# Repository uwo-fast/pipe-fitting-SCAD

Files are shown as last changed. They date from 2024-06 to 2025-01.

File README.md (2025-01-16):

# pipe-fitting-SCAD

OpenSCAD script for generating pipe fittings parametrically.

## Overview

This repository contains a script for modeling a pipe fitting assembly, complete with gaskets, threaded nuts, and customizable pipe fittings. The script is designed for use in OpenSCAD and offers extensive customization for each component while adhering to existing industry thread standards.

**Note:** By using this library, you accept full personal responsibility for its use and any resulting outcomes, and irrevocably agree to the terms outlined in the [legal disclaimer](docs/DISCLAIMER.md). _In short, you are agreeing to assume all risks associated with its use._

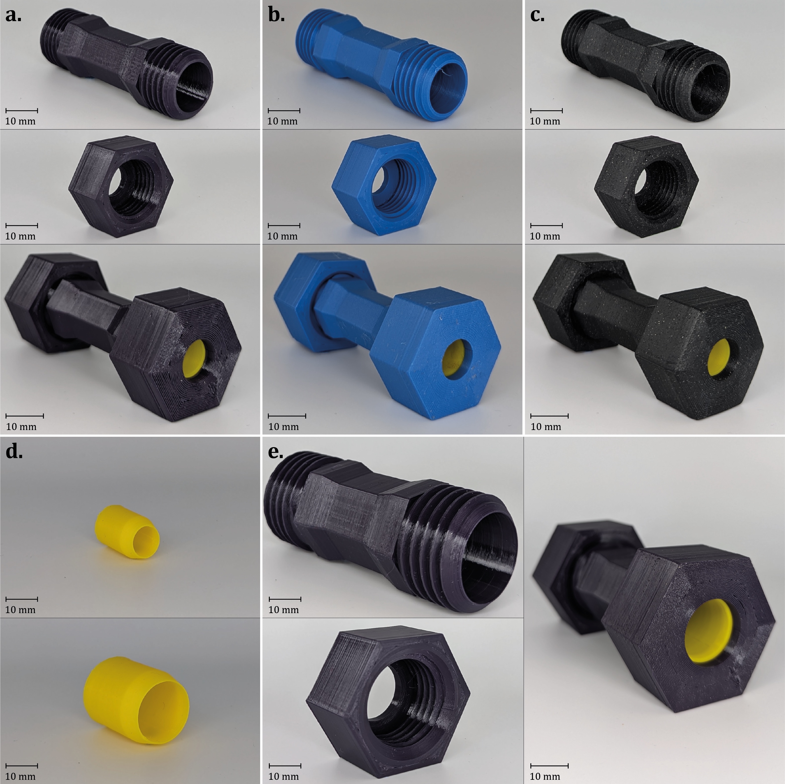
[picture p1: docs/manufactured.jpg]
Images of the Manufactured Pipe Fitting 1


## Dependencies

- OpenSCAD software.
- `threadlib` library by adrianschlatter, available at [adrianschlatter/threadlib](https://github.com/adrianschlatter/threadlib).

## Installation

1. Ensure OpenSCAD is installed on your system.
2. Download the `threadlib` library as well as this `pipe-fitting-scad` library.
3. Place both libraries in the OpenSCAD libraries directory (typically at `C:\Program Files\OpenSCAD\libraries` on Windows).

## Usage

### Creating your Fitting

Modify the dimensional variables at the beginning of the pfDesigner.scad script to customize the pipe, gasket, fitting, nuts, and threads.

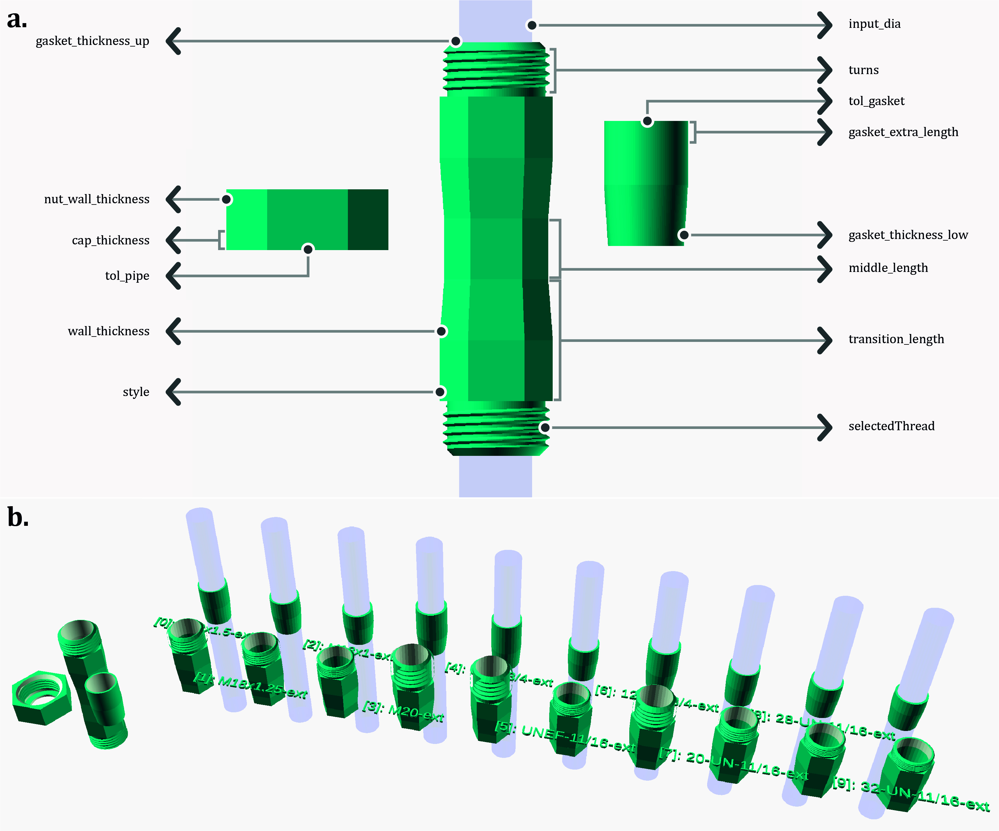
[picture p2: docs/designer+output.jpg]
Designer Interface and Labelled Output


### Manufacturing your Fitting

_Add part here about pettings and materials from paper._

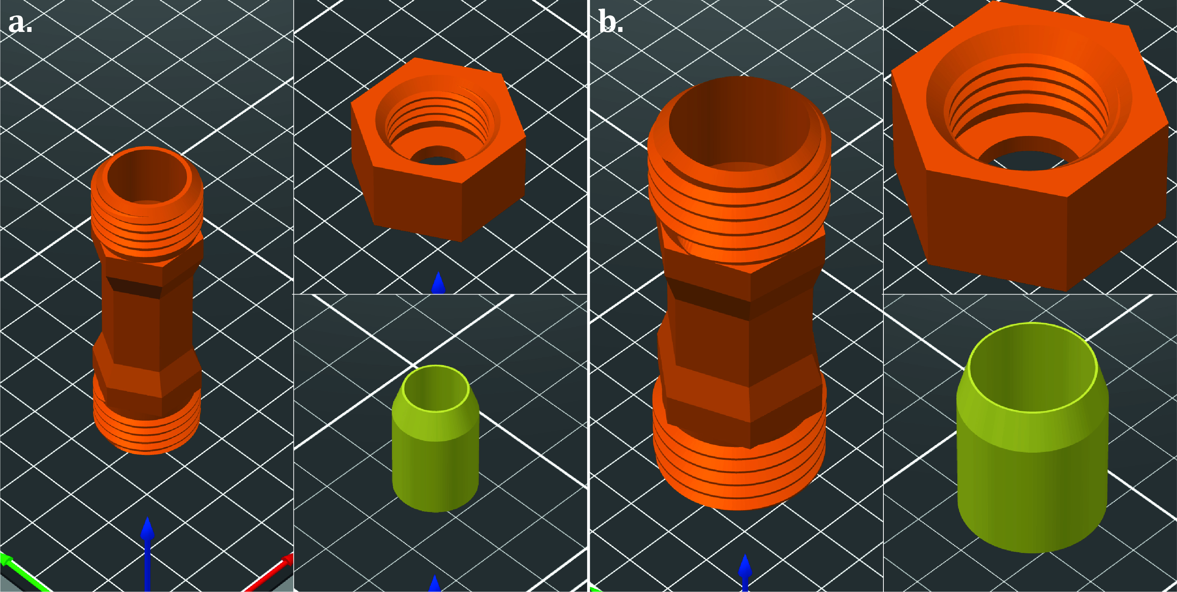
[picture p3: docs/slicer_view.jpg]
Slicer View for Manufacturing Fittings


### Performance Testing

NOTE THIS IS NOT A GAURENTEE OF SAFETY, ALWAYS CONDUCT YOUR OWN TESTING AND ALWAYS TAKE PROPER SAFETY PERCAUTIONS WHEN WORKING WITH HIGH PRESSURES.
_Add a laymans terms of the results from the paper here._

Fractured Print After Being Subject to Pressure

## How it Works

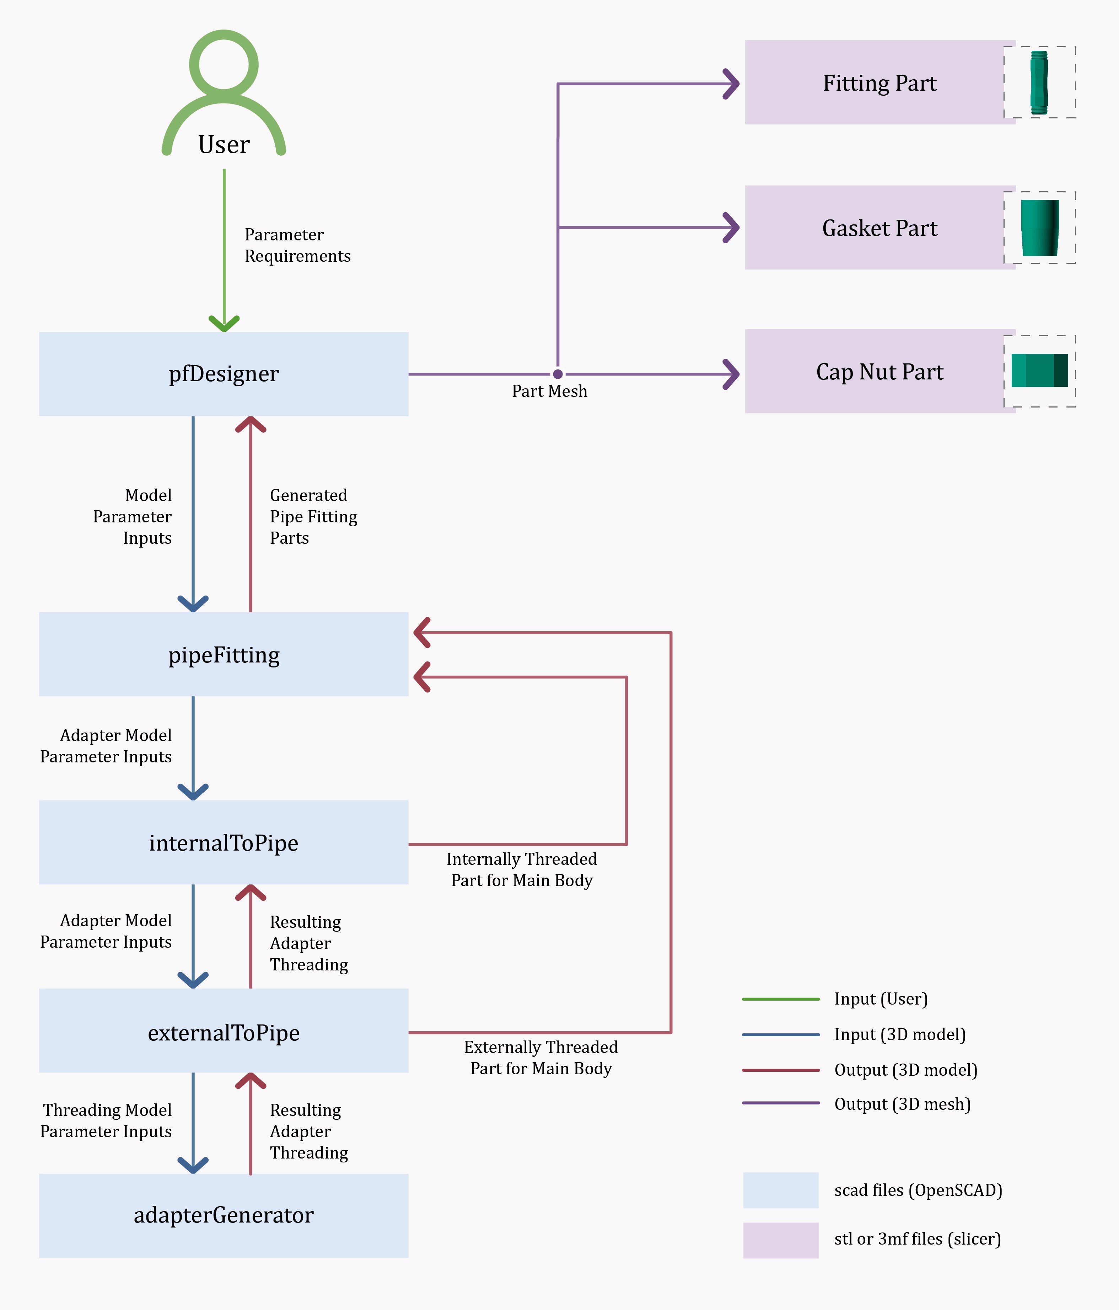
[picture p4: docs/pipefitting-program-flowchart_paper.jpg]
Programming Overview Flowchart


## Contributing & Requests

Contributions to improve the script or extend its capabilities are welcome. Please submit pull requests with clear descriptions of changes and additions. Similarly, submit an issue to request a fix or addition with a clear description of the bug or feature to be addressed.

## License

This script is licensed under the GPL 3.0 or later. For more details, see the [LICENSE](LICENSE) file.

## Acknowledgement

This was originally created by Cameron Brooks under the auspices of [FAST Research Group](https://www.appropedia.org/FAST) and published in [add when published]. This design uses [threadlib by Adrian Schlatter](https://github.com/adrianschlatter/threadlib) and inspiration from [Makrokaba's pipe joint generator](https://www.thingiverse.com/thing:4323468/files).

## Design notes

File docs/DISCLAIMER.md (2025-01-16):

# Legal Disclaimer

**By using this script and the associated files in this repository, you agree to the following terms and conditions. If you do not agree with these terms, you must immediately discontinue use of the repository and its contents.**

## 1. No Warranty

This repository, including the script and all associated files, is provided "as is," without any warranty of any kind, express or implied, including but not limited to the warranties of merchantability, fitness for a particular purpose, and non-infringement. The authors make no representations or warranties that the script will meet your requirements, be error-free, or function without interruption.

## 2. No Liability

The authors of this repository are not responsible for any damages, including but not limited to, direct, indirect, incidental, special, or consequential damages, or any loss of profits, data, or goodwill, arising from the use of this repository, even if the authors have been advised of the possibility of such damages. By using this repository, you agree to indemnify, defend, and hold harmless the authors from any claims or legal actions arising out of your use of the script or its results.

## 3. Use at Your Own Risk

The pipe fitting script, when used for 3D printing or other manufacturing methods, may result in a physical product that could fail under certain conditions, including but not limited to mechanical stress, pressure, temperature variations, or manufacturing defects. The use of this repository for creating pipe fittings or similar components is entirely at your own risk. You are responsible for ensuring the safety and integrity of any 3D printed models and components, especially in applications involving high pressures or other hazardous conditions.

## 4. Testing and Verification

The results and tests presented in this repository are provided for informational purposes only. The authors do not guarantee the safety, performance, or reliability of any 3D printed pipe fitting created using this script. It is your responsibility to perform proper testing and validation of any components you produce with this script, including pressure testing and other safety assessments. Always take appropriate safety precautions when working with high-pressure systems.

## 5. Customization and Modifications

You are permitted to modify and adapt the script to suit your needs, provided that all modifications remain subject to the terms of the GPL 3.0 license. However, any modifications or use of the repository do not absolve you of responsibility for any potential consequences arising from your use or the use of modified versions of this repository.

## 6. Compliance with Local Laws and Regulations

You are responsible for ensuring that your use of this repository and any resulting products comply with applicable laws, regulations, and safety standards in your jurisdiction. This includes, but is not limited to, compliance with engineering standards, manufacturing practices, and safety regulations for pressure vessels, piping systems, and materials.

## 7. Limitation of Use

This script is intended for use by individuals with appropriate knowledge of 3D printing, parametric design, and relevant safety protocols. It is not intended for use in mission-critical, life-threatening, or safety-critical applications. The authors disclaim any responsibility for any such usage.

## 8. Acknowledgement

By using this repository, you acknowledge that you have read and understood this legal disclaimer and agree to be bound by its terms. If you do not agree to these terms, you must refrain from using the repository or its contents.

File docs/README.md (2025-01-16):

# Docs

Welcome to the docs, right now there's not much here but that will change very soon!

## Considerations

General Considerations for 3D Printed Plumbing and HVAC Connectors:

- **Material Selection:** Must be durable, able to withstand the temperatures and pressures of refrigerant gases, and resistant to chemical degradation.

- **Dimensional Accuracy:** Essential for ensuring that fittings are leak-proof and compatible with existing pipes and components.

- **Structural Integrity:** The connectors must be able to withstand mechanical stresses without failing.

- **Compatibility with Seals and Gaskets:** Surfaces should be smooth to not damage any seals or gaskets they come into contact with.

- **Regulatory Compliance:** Must meet industry standards for safety and performance.

- **Post-Processing:** Some printed parts may require additional processing, such as threading or smoothing, to ensure proper function.

- **Testing:** Prototypes should be rigorously tested for pressure and leaks before being implemented in actual systems.

## Current Compatible Threads from threadslib

Compatible Threads:
[G1/16, G1/8, G1/4, G3/8, G1/2, G5/8, G3/4, G7/8, G1, G1 1/8, G1 1/4, G1 1/2, G1 3/4, G2, G2 1/4, G2 1/2,
G2 3/4, G3, G3 1/2, G4, G4 1/2, G5, G5 1/2, G6, M0.25x0.075, M0.3x0.08, M0.3x0.09, M0.35x0.09, M0.4x0.1,
M0.45x0.1, M0.5x0.125, M0.55x0.125, M0.6x0.15, M0.7x0.175, M0.8x0.2, M0.9x0.225, M1, M1x0.2, M1.1x0.25,
M1.1x0.2, M1.2, M1.2x0.2, M1.4, M1.4x0.2, M1.6, M1.6x0.3, M1.6x0.2, M1.7x0.35, M1.8, M1.8x0.2, M2,
M2x0.25, M2.2, M2.2x0.25, M2.3x0.45, M2.3x0.4, M2.5, M2.5x0.35, M2.6x0.45, M3, M3x0.35, M3.5, M3.5x0.35,
M4, M4x0.5, M4.5x0.75, M4.5x0.5, M5, M5x0.5, M5.5x0.5, M6, M6x0.8, M6x0.75, M6x0.7, M6x0.5, M7, M7x0.75,
M7x0.5, M8, M8x1, M8x0.8, M8x0.75, M8x0.5, M9x1.25, M9x1, M9x0.75, M9x0.5, M10, M10x1.25, M10x1.12,
M10x1, M10x0.75, M10x0.5, M11x1.5, M11x1, M11x0.75, M11x0.5, M12, M12x1.5, M12x1.25, M12x1, M12x0.75,
M12x0.5, M14, M14x1.5, M14x1.25, M14x1, M14x0.75, M14x0.5, M15x1.5, M15x1, M16, M16x1.6, M16x1.5,
M16x1.25, M16x1, M16x0.75, M16x0.5, M17x1.5, M17x1, M18, M18x2, M18x1.5, M18x1.25, M18x1, M18x0.75,
M18x0.5, M20, M20x2, M20x1.5, M20x1, M20x0.75, M20x0.5, M22x3, M22, M22x2, M22x1.5, M22x1, M22x0.75,
M22x0.5, M24, M24x2.5, M24x2, M24x1.5, M24x1, M24x0.75, M25x2, M25x1.5, M25x1, M26x1.5, M27, M27x2,
M27x1.5, M27x1, M27x0.75, M28x2, M28x1.5, M28x1, M30, M30x3, M30x2.5, M30x2, M30x1.5, M30x1, M30x0.75,
M32x2, M32x1.5, M33, M33x3, M33x2, M33x1.5, M33x1, M33x0.75, M35x1.5, M36, M36x3, M36x2, M36x1.5, M36x1,
M38x1.5, M39, M39x3, M39x2, M39x1.5, M39x1, M40x3, M40x2.5, M40x2, M40x1.5, M42, M42x4, M42x3, M42x2,
M42x1.5, M42x1, M45, M45x4, M45x3, M45x2, M45x1.5, M45x1, M48, M48x4, M48x3, M48x2, M48x1.5, M50x4,
M50x3, M50x2, M50x1.5, M52, M52x4, M52x3, M52x2, M52x1.5, M55x4, M55x3, M55x2, M55x1.5, M56, M56x4,
M56x3, M56x2, M56x1.5, M56x1, M58x4, M58x3, M58x2, M58x1.5, M60, M60x4, M60x3, M60x2, M60x1.5, M60x1,
M62x4, M62x3, M62x2, M62x1.5, M63x1.5, M64, M64x5.5, M64x4, M64x3, M64x2, M64x1.5, M64x1, M65x4, M65x3,
M65x2, M65x1.5, M68x6, M68x4, M68x3, M68x2, M68x1.5, M68x1, M70x6, M70x4, M70x3, M70x2, M70x1.5, M72x6,
M72x4, M72x3, M72x2, M72x1.5, M72x1, M75x6, M75x4, M75x3, M75x2, M75x1.5, M76x6, M76x4, M76x3, M76x2,
M76x1.5, M76x1, M78x2, M80x6, M80x4, M80x3, M80x2, M80x1.5, M80x1, M82x2, M85x6, M85x4, M85x3, M85x2,
M85x1.5, M90x6, M90x4, M90x3, M90x2, M90x1.5, M95x6, M95x4, M95x3, M95x2, M95x1.5, M100x6, M100x4,
M100x3, M100x2, M100x1.5, M105x6, M105x4, M105x3, M105x2, M105x1.5, M110x6, M110x4, M110x3, M110x2,
M110x1.5, M115x6, M115x4, M115x3, M115x2, M115x1.5, M120x6, M120x4, M120x3, M120x2, M120x1.5, M125x8,
M125x6, M125x4, M125x3, M125x2, M125x1.5, M130x8, M130x6, M130x4, M130x3, M130x2, M130x1.5, M135x6,
M135x4, M135x3, M135x2, M135x1.5, M140x8, M140x6, M140x4, M140x3, M140x2, M140x1.5, M145x6, M145x4,
M145x3, M145x2, M145x1.5, M150x8, M150x6, M150x4, M150x3, M150x2, M150x1.5, M155x6, M155x4, M155x3,
M155x2, M160x8, M160x6, M160x4, M160x3, M160x2, M165x6, M165x4, M165x3, M165x2, M170x8, M170x6, M170x4,
M170x3, M170x2, M175x6, M175x4, M175x3, M175x2, M180x8, M180x6, M180x4, M180x3, M180x2, M185x6, M185x4,
M185x3, M185x2, M190x8, M190x6, M190x4, M190x3, M190x2, M195x6, M195x4, M195x3, M195x2, M200x8, M200x6,
M200x4, M200x3, M200x2, M205x6, M205x4, M205x3, M205x2, M210x8, M210x6, M210x4, M210x3, M210x2, M215x6,
M215x4, M215x3, M220x8, M220x6, M220x4, M220x3, M220x2, M225x6, M225x4, M225x3, M225x2, M230x6, M230x4,
M230x3, M230x2, M235x6, M235x4, M235x3, M240x8, M240x6, M240x4, M240x3, M240x2, M245x6, M245x4, M245x3,
M245x2, M250x8, M250x6, M250x4, M250x3, M250x2, M255x6, M255x4, M255x3, M260x8, M260x6, M260x4, M260x3,
M265x6, M265x4, M265x3, M270x6, M270x4, M270x3, M275x6, M275x4, M275x3, M280x8, M280x6, M280x4, M280x3,
M285x6, M285x4, M285x3, M290x6, M290x4, M290x3, M295x6, M295x4, M295x3, M300x8, M300x6, M300x4, M300x3,
M310x6, M310x4, M320x6, M320x4, M330x6, M330x4, M340x6, M340x4, M350x6, M350x4, M360x6, M360x4, M370x6,
M370x4, M380x6, M380x4, M390x6, M390x4, M400x6, M400x4, M410x6, M420x6, M430x6, M440x6, M450x6, M460x6,
M470x6, M480x6, M490x6, M500x6, M510x6, M520x6, M530x6, M540x6, M550x6, M560x6, M570x6, M580x6, M590x6,
M600x6, PCO-1881, UNC-#1, UNC-#2, UNC-#3, UNC-#4, UNC-#5, UNC-#6, UNC-#8, UNC-#10, UNC-#12, UNC-1/4,
UNC-5/16, UNC-3/8, UNC-7/16, UNC-1/2, UNC-9/16, UNC-5/8, UNC-3/4, UNC-7/8, UNC-1, UNC-1 1/8, UNC-1 1/4,
UNC-1 3/8, UNC-1 1/2, UNC-1 3/4, UNC-2, UNC-2 1/4, UNC-2 1/2, UNC-2 3/4, UNC-3, UNC-3 1/4, UNC-3 1/2,
UNC-3 3/4, UNC-4, UNF-#0, UNF-#1, UNF-#2, UNF-#3, UNF-#4, UNF-#5, UNF-#6, UNF-#8, UNF-#10, UNF-#12,
UNF-1/4, UNF-5/16, UNF-3/8, UNF-7/16, UNF-1/2, UNF-9/16, UNF-5/8, UNF-3/4, UNF-7/8, UNF-1, UNF-1 1/8,
UNF-1 1/4, UNF-1 3/8, UNF-1 1/2, UNEF-#12, UNEF-1/4, UNEF-5/16, UNEF-3/8, UNEF-7/16, UNEF-1/2, UNEF-9/16,
UNEF-5/8, UNEF-11/16, UNEF-3/4, UNEF-13/16, UNEF-7/8, UNEF-15/16, UNEF-1, UNEF-1 1/16, UNEF-1 1/8, UNEF-1
3/16, UNEF-1 1/4, UNEF-1 5/16, UNEF-1 3/8, UNEF-1 7/16, UNEF-1 1/2, UNEF-1 9/16, UNEF-1 5/8, UNEF-1
11/16, 4-UN-2 1/2, 4-UN-2 5/8, 4-UN-2 3/4, 4-UN-2 7/8, 4-UN-3, 4-UN-3 1/8, 4-UN-3 1/4, 4-UN-3 3/8, 4-UN-3
1/2, 4-UN-3 5/8, 4-UN-3 3/4, 4-UN-3 7/8, 4-UN-4, 4-UN-4 1/8, 4-UN-4 1/4, 4-UN-4 3/8, 4-UN-4 1/2, 4-UN-4
5/8, 4-UN-4 3/4, 4-UN-4 7/8, 4-UN-5, 4-UN-5 1/8, 4-UN-5 1/4, 4-UN-5 3/8, 4-UN-5 1/2, 4-UN-5 5/8, 4-UN-5
3/4, 4-UN-5 7/8, 4-UN-6, 6-UN-1 3/8, 6-UN-1 7/16, 6-UN-1 1/2, 6-UN-1 9/16, 6-UN-1 5/8, 6-UN-1 11/16,
6-UN-1 3/4, 6-UN-1 13/16, 6-UN-1 7/8, 6-UN-1 15/16, 6-UN-2, 6-UN-2 1/8, 6-UN-2 1/4, 6-UN-2 3/8, 6-UN-2
1/2, 6-UN-2 5/8, 6-UN-2 3/4, 6-UN-2 7/8, 6-UN-3, 6-UN-3 1/8, 6-UN-3 1/4, 6-UN-3 3/8, 6-UN-3 1/2, 6-UN-3
5/8, 6-UN-3 3/4, 6-UN-3 7/8, 6-UN-4, 6-UN-4 1/8, 6-UN-4 1/4, 6-UN-4 3/8, 6-UN-4 1/2, 6-UN-4 5/8, 6-UN-4
3/4, 6-UN-4 7/8, 6-UN-5, 6-UN-5 1/8, 6-UN-5 1/4, 6-UN-5 3/8, 6-UN-5 1/2, 6-UN-5 5/8, 6-UN-5 3/4, 6-UN-5
7/8, 6-UN-6, 8-UN-1, 8-UN-1 1/16, 8-UN-1 1/8, 8-UN-1 3/16, 8-UN-1 1/4, 8-UN-1 5/16, 8-UN-1 3/8, 8-UN-1
7/16, 8-UN-1 1/2, 8-UN-1 9/16, 8-UN-1 5/8, 8-UN-1 11/16, 8-UN-1 3/4, 8-UN-1 13/16, 8-UN-1 7/8, 8-UN-1
15/16, 8-UN-2, 8-UN-2 1/8, 8-UN-2 1/4, 8-UN-2 3/8, 8-UN-2 1/2, 8-UN-2 5/8, 8-UN-2 3/4, 8-UN-2 7/8,
8-UN-3, 8-UN-3 1/8, 8-UN-3 1/4, 8-UN-3 3/8, 8-UN-3 1/2, 8-UN-3 5/8, 8-UN-3 3/4, 8-UN-3 7/8, 8-UN-4,
8-UN-4 1/8, 8-UN-4 1/4, 8-UN-4 3/8, 8-UN-4 1/2, 8-UN-4 5/8, 8-UN-4 3/4, 8-UN-4 7/8, 8-UN-5, 8-UN-5 1/8,
8-UN-5 1/4, 8-UN-5 3/8, 8-UN-5 1/2, 8-UN-5 5/8, 8-UN-5 3/4, 8-UN-5 7/8, 8-UN-6, 12-UN-9/16, 12-UN-5/8,
12-UN-11/16, 12-UN-3/4, 12-UN-13/16, 12-UN-7/8, 12-UN-15/16, 12-UN-1, 12-UN-1 1/16, 12-UN-1 1/8, 12-UN-1
3/16, 12-UN-1 1/4, 12-UN-1 5/16, 12-UN-1 3/8, 12-UN-1 7/16, 12-UN-1 1/2, 12-UN-1 9/16, 12-UN-1 5/8,
12-UN-1 11/16, 12-UN-1 3/4, 12-UN-1 13/16, 12-UN-1 7/8, 12-UN-1 15/16, 12-UN-2, 12-UN-2 1/8, 12-UN-2 1/4,
12-UN-2 3/8, 12-UN-2 1/2, 12-UN-2 5/8, 12-UN-2 3/4, 12-UN-2 7/8, 12-UN-3, 12-UN-3 1/8, 12-UN-3 1/4,
12-UN-3 3/8, 12-UN-3 1/2, 12-UN-3 5/8, 12-UN-3 3/4, 12-UN-3 7/8, 12-UN-4, 12-UN-4 1/8, 12-UN-4 1/4,
12-UN-4 3/8, 12-UN-4 1/2, 12-UN-4 5/8, 12-UN-4 3/4, 12-UN-4 7/8, 12-UN-5, 12-UN-5 1/8, 12-UN-5 1/4,
12-UN-5 3/8, 12-UN-5 1/2, 12-UN-5 5/8, 12-UN-5 3/4, 12-UN-5 7/8, 12-UN-6, 16-UN-3/8, 16-UN-7/16,
16-UN-1/2, 16-UN-9/16, 16-UN-5/8, 16-UN-11/16, 16-UN-3/4, 16-UN-13/16, 16-UN-7/8, 16-UN-15/16, 16-UN-1,
16-UN-1 1/16, 16-UN-1 1/8, 16-UN-1 3/16, 16-UN-1 1/4, 16-UN-1 5/16, 16-UN-1 3/8, 16-UN-1 7/16, 16-UN-1
1/2, 16-UN-1 9/16, 16-UN-1 5/8, 16-UN-1 11/16, 16-UN-1 3/4, 16-UN-1 13/16, 16-UN-1 7/8, 16-UN-1 15/16,
16-UN-2, 16-UN-2 1/8, 16-UN-2 1/4, 16-UN-2 3/8, 16-UN-2 1/2, 16-UN-2 5/8, 16-UN-2 3/4, 16-UN-2 7/8,
16-UN-3, 16-UN-3 1/8, 16-UN-3 1/4, 16-UN-3 3/8, 16-UN-3 1/2, 16-UN-3 5/8, 16-UN-3 3/4, 16-UN-3 7/8,
16-UN-4, 16-UN-4 1/8, 16-UN-4 1/4, 16-UN-4 3/8, 16-UN-4 1/2, 16-UN-4 5/8, 16-UN-4 3/4, 16-UN-4 7/8,
16-UN-5, 16-UN-5 1/8, 16-UN-5 1/4, 16-UN-5 3/8, 16-UN-5 1/2, 16-UN-5 5/8, 16-UN-5 3/4, 16-UN-5 7/8,
16-UN-6, 20-UN-1/4, 20-UN-5/16, 20-UN-3/8, 20-UN-7/16, 20-UN-1/2, 20-UN-9/16, 20-UN-5/8, 20-UN-11/16,
20-UN-3/4, 20-UN-13/16, 20-UN-7/8, 20-UN-15/16, 20-UN-1, 20-UN-1 1/16, 20-UN-1 1/8, 20-UN-1 3/16, 20-UN-1
1/4, 20-UN-1 5/16, 20-UN-1 3/8, 20-UN-1 7/16, 20-UN-1 1/2, 20-UN-1 9/16, 20-UN-1 5/8, 20-UN-1 11/16,
20-UN-1 3/4, 20-UN-1 13/16, 20-UN-1 7/8, 20-UN-1 15/16, 20-UN-2, 20-UN-2 1/8, 20-UN-2 1/4, 20-UN-2 3/8,
20-UN-2 1/2, 20-UN-2 5/8, 20-UN-2 3/4, 20-UN-2 7/8, 20-UN-3, 28-UN-#12, 28-UN-1/4, 28-UN-5/16, 28-UN-3/8,
28-UN-7/16, 28-UN-1/2, 28-UN-9/16, 28-UN-5/8, 28-UN-11/16, 28-UN-3/4, 28-UN-13/16, 28-UN-7/8,
28-UN-15/16, 28-UN-1, 28-UN-1 1/16, 28-UN-1 1/8, 28-UN-1 3/16, 28-UN-1 1/4, 28-UN-1 5/16, 28-UN-1 3/8,
28-UN-1 7/16, 28-UN-1 1/2, 32-UN-#6, 32-UN-#8, 32-UN-#10, 32-UN-#12, 32-UN-1/4, 32-UN-5/16, 32-UN-3/8,
32-UN-7/16, 32-UN-1/2, 32-UN-9/16, 32-UN-5/8, 32-UN-11/16, 32-UN-3/4, 32-UN-13/16]

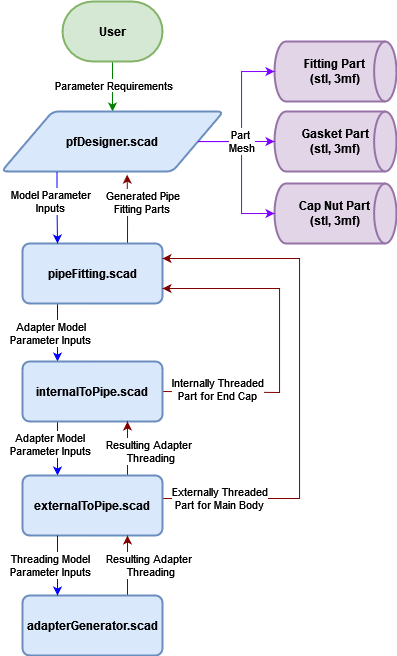
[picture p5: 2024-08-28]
docs/pipefitting-program-flowchart.png

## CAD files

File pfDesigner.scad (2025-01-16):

// pipeFittingDesigner.scad

include <threadlib/THREAD_TABLE.scad>
use <threadlib/threadlib.scad>;

use <adaptersMod/externalToPipe.scad>;
use <adaptersMod/internalToPipe.scad>;
use <pipeFitting.scad>;

// ----------------------------
// -------- Parameters --------
// ----------------------------

// The input diameter for the pipe(s) being coupled
input_dia = 12.00;

// The upper and lower limits for the desired gasket thickness
// Used along with input_dia to determine valid thread types
gasket_thickness_upper = 15;
gasket_thickness_lower = 13;

gasket_extra_length = 3; // Allows addition of extra length to the gasket to ensure a tight fit

// Tolerance between the input pipe(s) and the main fitting part and nut part
tol_pipe = 0.2;

// Tolerance between the input pipe(s) and the gasket(s)
tol_gasket = 0.1;

turns = 5;

// Wall thickness of the fitting parts
wall_thickness = 1.2;

// Lower part length, length of the center tube is lower_length * 2
middle_length = 20.0;

// Mid part height between the upper part where the thread
// is and lower part that makes up the center tube
transition_length = 15.0;

// Cap thickness for the fitting nut
cap_thickness = 1.0;
nut_wall_thickness = 2.4;

// Entry chamfer for the fitting mate
entry_chamfer = true;

// The style of the fitting
style = "Hexagon"; // "Hexagon", "Cone", "Circular"

// see the <<<ECHO: "SHOWING[0/X]:">>> for the number of available threads X
// based on your above specifications
selectedThread = 5;

export = true;        // when true derenders all but the selected 'selectedPart'
selectedPart = "all"; // show the fitting, nut, gasket, or all

showInputPipe = false; // show the input pipe(s) for reference

// ----------------------------
// ------ End Parameters ------
// ----------------------------

// ----------------------------
// ----- Global Variables -----
// ----------------------------

// full circle has 120 fragments
$fn = $preview ? 120 * 1 / 4 : 120 * 1;
// correction factor for circle subtraction to avoid undersized holes
fudge = 1 / cos(180 / $fn);
corrector = 0.15;

lower_length = middle_length / 2;
mid_height = transition_length / 2;

// ----------------------------
// --- End Global Variables ---
// ----------------------------

// ----------------------------
// ----- Design Solutions -----
// ----------------------------

// Designators for external threads within gasket thicknesses ranges
designators = thread_specD("ext", (input_dia + gasket_thickness_lower / 2), (input_dia + gasket_thickness_upper / 2));

if (!export)
{
    translate([ thread_specs(designators[0])[2] * 2, thread_specs(designators[0])[2] * 2, 0 ])
    {
        for (i = [0:len(designators) - 1])
        {
            echo(designators[i]);
            specs = thread_specs(designators[i]);
            pitch = specs[0];
            Dsupport = specs[2];
            DsuppTogg = i % 2 == 0 ? Dsupport : -Dsupport; // Toggle Dsupport
            lower_outer_to_inner_corr = input_dia + wall_thickness * 2 + tol_pipe * 2;
            translate([ input_dia * 3 * i, 0, 0 ])
            {
                Adapter_External_Bare(corrector, // corrector
                                      designators[i], turns, wall_thickness,
                                      entry_chamfer,              // Upper External Thread Part
                                      style, 0, mid_height, 0, 0, // Middle Part
                                      lower_outer_to_inner_corr, wall_thickness, lower_length // Lower Part
                );
                translate([ 0, DsuppTogg, 0 ])
                    text(text = str("[", i, "]: ", designators[i]), size = 5, halign = "center", valign = "center");
            }

            translate([ input_dia * 3 * i, Dsupport * 2, -mid_height / 2 ])
            {
                color(c = "blue", alpha = 0.1) translate([ 0, 0, -input_dia * 5 ])
                    cylinder(h = input_dia * 10, d = input_dia);
                generateGasket(designator = designators[i], mid_height = mid_height, wall_thickness = wall_thickness,
                               fudge = fudge, turns = turns, input_dia = input_dia, fit_excess = gasket_extra_length,
                               tol_gasket = tol_gasket, tol_pipe = tol_pipe);
            }
        }
    }
}

// ----------------------------
// --- End Design Solutions ---
// ----------------------------

// ----------------------------
// ----- Design Selection -----
// ----------------------------

thread_type_select = designators[selectedThread];
echo(str("SHOWING", "[", selectedThread, "/", len(designators), "]", ":"));
echo(thread_type_select);

if (!export || (selectedPart == "fitting" || selectedPart == "all"))
{
    generateFitting(corrector = corrector, thread_type = thread_type_select, input_dia = input_dia, turns = turns,
                    wall_thickness = wall_thickness, tol_pipe = tol_pipe, entry_chamfer = entry_chamfer, style = style,
                    mid_height = mid_height, lower_length = lower_length);
    if (showInputPipe)
    {
        color(c = "blue", alpha = 10) cylinder(
            h = (middle_length + transition_length * 2 + (turns + 1) * thread_specs(thread_type_select)[0] * 2) +
                input_dia * 4,
            d = input_dia, center = true);
    }
}

if (!export || (selectedPart == "nut" || selectedPart == "all"))
{
    translate([ -thread_specs(thread_type_select)[2], -thread_specs(thread_type_select)[2], 0 ])
        generateNut(corrector = corrector, thread_type = thread_type_select, turns = turns,
                    wall_thickness = nut_wall_thickness, entry_chamfer = entry_chamfer, style = style,
                    cap_thickness = cap_thickness, input_dia = input_dia, tol_pipe = tol_pipe, fudge = fudge);
}

if (!export || (selectedPart == "gasket" || selectedPart == "all"))
{
    translate([ thread_specs(thread_type_select)[2], -thread_specs(thread_type_select)[2], 0 ])
        generateGasket(corrector = corrector, designator = thread_type_select, mid_height = mid_height,
                       wall_thickness = wall_thickness, fudge = fudge, turns = turns, input_dia = input_dia,
                       fit_excess = gasket_extra_length, tol_gasket = tol_gasket, tol_pipe = tol_pipe);
}

// ----------------------------
// --- End Design Selection ---
// ----------------------------

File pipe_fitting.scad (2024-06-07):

/*
 * Title: [Pipe Fitting and Gasket Assembly]
 * Author: Cameron K. Brooks
 * Organization: FAST Research Group
 * Date: [2023-12-29]
 * License: GPL 3.0 or later
 *
 * Description:
 * This script models a comprehensive pipe fitting assembly, including gaskets, threaded nuts, and customizable pipe fittings. 
 * The script now includes new modules for detailed modeling of pipe inputs, main fittings, nuts, and gaskets. 
 *
 * Dependencies:
 * ADD !!!!!!!!!!!!!!!!
 *
 * Usage Notes:
 * Update dimensional variables at the beginning of the script to modify the pipe, gasket, fitting, nuts, and threads. The script caters to a wide range of specifications and is adaptable for various engineering applications.
 *
 * Parameters:
 * - Pipe: length, diameter, thickness, extension, gasket seat depth, tolerance, 
 * - Main Fitting: pipe fitting diameter, length, gasket seat width, depth, thread length, middle section distance, outer diameter, tolerance, surface details
 * - Nuts and Gaskets: outer diameter, fit diameter, tolerance, end thickness, circle depression, spacing, gasket depth, minimum thickness, width
 *
 * Revision History:
 * [2023-11-20 - Initial version]
 * [2023-12-29 - Major revision with addition of new modules and parameters]
 */


use <threads-scad\threads.scad>;

$fn=16;

def_diameter = 10;

module inputPipes(diameter=def_diameter, thickness=undef) {
    z_fite = $preview ? 0.05 : 0;
    thickness = is_undef(thickness) ? diameter / 10 : thickness;    


    union() {
        // First cylinder
        color("LightCoral")
        difference() {
            cylinder(h=diameter*10, r1=diameter/2, r2=diameter/2);

            translate([0,0,-z_fite]) 
            cylinder(h=diameter*10 + z_fite*2, r1=diameter/2 - thickness/2, r2=diameter/2 - thickness/2);
        }

        translate([0,0,-diameter*10])
        // Second cylinder
        color("PowderBlue")
        difference() {
            cylinder(h=diameter*10, r1=diameter/2, r2=diameter/2);

            translate([0,0,-z_fite]) 
            cylinder(h=diameter*10 + z_fite*2, r1=diameter/2 - thickness/2, r2=diameter/2 - thickness/2);
        }
    }
}

inputPipes();



/*

1. **P vs D**: P = 0.54D + 6.51 

2. **L vs D**: L = 1.35D - 23.11

3. **G vs D**: G = 0.24D - 3.69 

4. **B vs D**: B = 0.24D - 0.40

5. **B0 vs D**: B0 = 0.26D - 0.17

-------------------------------

1. **P vs D**: 
P = 0.55D + 6.5

2. **L vs D**: 
L = 1.35D - 23.0

3. **G vs D**: 
G = 0.25D - 3.5

4. **B vs D**: 
B = 0.1D - 0.40

5. **B0 vs D**: 
B0 = 0.25D - 0.15

*/
module mainFitting(
    pipe_dia = def_diameter, 
    pipe_tol = undef,
    gasket_dia1 = undef, 
    gasket_dia2 = undef, 
    gasket_height = undef, 
    thread_length = undef,
    thread_tol = undef, 
    thread_pitch = undef,
    thread_tooth_height = undef,
    pipe_surfaces = 8, 
) {
    z_fite = $preview ? 0.05 : 0;

    pipe_fit_length = 0.25*pipe_dia - 0.15;
    pipe_fit_dia = pipe_dia + pipe_tol;



    thread_length = 0.25*pipe_dia - 0.15;

    gasket_dia1 = undef, 
    gasket_height = thread_length/2;

    fitting_total_length = pipe_fit_length + gasket_height * 2;

    middle_section_distance = fitting_total_length - thread_length * 2;

    middle_section_outer_dia = pipe_fit_dia + gasket_dia1*2;

    fitting_total_outer_dia = middle_section_outer_dia + thread_depth;


    color("DarkSlateGray", alpha=1.0) 
    difference() {
        union() {
            ScrewThread(fitting_total_outer_dia, thread_length, tolerance=thread_tol, tip_height=2, tip_min_fract=3/4);
            cylinder(h=thread_length, r=fitting_total_outer_dia/2-thread_tol);

            translate([0,0,thread_length]) 
            cylinder(middle_section_distance, middle_section_outer_dia/2, middle_section_outer_dia/2, $fn=pipe_surfaces);
            
            translate([0,0,middle_section_distance+thread_length+thread_length]) 
            rotate([180,0,0]) 
            ScrewThread(fitting_total_outer_dia, thread_length, tolerance=thread_tol, tip_height=2, tip_min_fract=3/4);
        }

        translate([0,0,0]) 
        union() {
            translate([0,0,-z_fite]) 
            cylinder(gasket_height+z_fite, (pipe_fit_dia+gasket_dia1 * 2)/2, pipe_fit_dia/2);
            translate([0,0,gasket_height]) 
            cylinder(pipe_fit_length, pipe_fit_dia/2, pipe_fit_dia/2);
            translate([0,0,gasket_height+pipe_fit_length+gasket_height+z_fite]) 
            rotate([180,0,0]) 
            cylinder(gasket_height+z_fite, (pipe_fit_dia+gasket_dia1*2)/2, pipe_fit_dia/2);
        }
    }
}

mainFitting();

module pfNut(
    pipe_dia = def_pipe_dia, 
    pipe_tol = def_pipe_tol,
    nut_end_thickness = def_nut_end_thickness, 
    nut_circle_depression = def_nut_circle_depression, 
    gasket_dia1 = def_gasket_dia1, 
    gasket_height = def_gasket_height, 
    thread_length = def_thread_length,
    thread_tol = def_thread_tol, 
    scale = 1,
) {
    z_fite = $preview ? 0.05 : 0;

    pipe_fit_dia = pipe_dia + pipe_tol;

    middle_section_outer_dia = pipe_fit_dia + gasket_dia1*2;
    fitting_total_outer_dia = middle_section_outer_dia ;

    outer_dia = fitting_total_outer_dia*scale;

    color("SteelBlue", alpha=0.5)
    union() {
        difference() {
            MetricNut(outer_dia, tolerance=thread_tol);
            translate([0,0,-z_fite]) 
            cylinder(nut_circle_depression+z_fite,outer_dia/2+nut_circle_depression*2,outer_dia/2+nut_circle_depression*2);
        }
        translate([0,0,NutThickness(outer_dia)]) 
        difference() {
            cylinder(h=nut_end_thickness, r=HexAcrossCorners(outer_dia)/2-0.5*thread_tol, $fn=6);
            translate([0,0,-z_fite]) 
            cylinder(NutThickness(outer_dia)+z_fite*2, pipe_fit_dia/2, pipe_fit_dia/2);
        }
    }
}

module pfGasket(
    pipe_dia = def_pipe_dia, 
    pipe_tol = def_pipe_tol,
    gasket_depth = def_gasket_depth,
    gasket_width = def_gasket_width,
    gasket_min_thickness = def_gasket_min_thickness,
    ) {
    z_fite = $preview ? 0.05 : 0;
    
    pipe_fit_dia = pipe_dia + pipe_tol;

    color("DarkGrey", alpha=0.5) 
    difference() {
        cylinder(gasket_depth, (pipe_fit_dia+gasket_min_thickness+gasket_width*2)/2, (pipe_fit_dia+gasket_min_thickness)/2);
        translate([0,0,-z_fite]) 
        cylinder(gasket_depth+z_fite*2, pipe_fit_dia/2, pipe_fit_dia/2);
    }
}

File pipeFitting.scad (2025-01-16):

// pipeFitting.scad

include <threadlib/THREAD_TABLE.scad>
use <threadlib/threadlib.scad>;

use <adaptersMod/externalToPipe.scad>;
use <adaptersMod/internalToPipe.scad>;

// Function to check if a string ends with a given suffix
function ends_with(str, suffix) = let(str_len = len(str), suffix_len = len(suffix))
                                  // Check each character manually
                                  (str_len >= suffix_len) &&
                                  [for (i = [0:suffix_len - 1]) str[str_len - suffix_len + i] == suffix[i]] ==
                                      [for (i = [0:suffix_len - 1]) true];

// Define the thread_specD function
function thread_specD(type, min_diameter, max_diameter) =
    let(filtered_rows = [for (row = THREAD_TABLE) if (
            (type == "int" && ends_with(row[0], "-int")) ||
            (type == "ext" && ends_with(row[0], "-ext"))) if (row[1][2] >= min_diameter && row[1][2] <= max_diameter)
                row[0]]) filtered_rows;

// Define the function to remove the last X characters
function remove_last_chars(str, num_chars) = substr(str, 0, max(0, len(str) - num_chars));

// Define the function to join a list of strings with a delimiter
function join(l, delimiter = "") = let(s = len(l), d = delimiter,
                                       jb = function(b, e) let(s = e - b, m = floor(b + s / 2)) // join binary
                                                    s > 2
                                                ? str(jb(b, m), jb(m, e))
                                            : s == 2 ? str(l[b], l[b + 1])
                                                     : l[b],
                                       jd = function(b, e) let(s = e - b, m = floor(b + s / 2)) // join delimiter
                                                    s > 2
                                                ? str(jd(b, m), d, jd(m, e))
                                            : s == 2 ? str(l[b], d, l[b + 1])
                                                     : l[b]) s
                                           > 0
                                       ? (d == "" ? jb(0, s) : jd(0, s))
                                       : "";

// Define the function to extract a substring from a string
function substr(s, b, e) = let(e = is_undef(e) || e > len(s) ? len(s) : e)(b == e) ? ""
                                                                                   : join([for (i = [b:1:e - 1]) s[i]]);

// generateGasket module to create a gasket for the pipe fitting
module generateGasket(corrector, designator, mid_height, wall_thickness, fudge, turns, input_dia, fit_excess,
                      tol_gasket, tol_pipe, z_fite = 0.05)
{
    // adapter generation uses external diameter, this maps to the inner diameter
    lower_outer_to_inner_corr = input_dia + wall_thickness * 2 + tol_pipe * 2;

    specs = thread_specs(designator);
    pitch = specs[0];
    Dsupport = specs[2];

    difference()
    {
        union()
        {
            cylinder(h = mid_height, r1 = (lower_outer_to_inner_corr / 2 - wall_thickness) * fudge,
                     r2 = (Dsupport / 2 - wall_thickness) * fudge, center = false);
            translate([ 0, 0, mid_height ])
                cylinder(h = (turns * pitch) + fit_excess, r = (Dsupport / 2 - wall_thickness) * fudge, center = false);
        }
        translate([ 0, 0, -z_fite / 2 ]) cylinder(h = mid_height + (turns * pitch) + fit_excess + z_fite,
                                                  r = (input_dia / 2 + tol_gasket) * fudge, center = false);
    }
}

// generateFitting module to create the pipe fitting
module generateFitting(corrector, thread_type, input_dia, turns, wall_thickness, tol_pipe, entry_chamfer, style,
                       mid_outer_diameter = 0, mid_height, lower_length)
{
    // adapter generation uses external diameter, this maps to the inner diameter
    lower_outer_to_inner_corr = input_dia + wall_thickness * 2 + tol_pipe * 2;

    Adapter_External_Bare(corrector, thread_type, turns, wall_thickness, entry_chamfer, // Upper External Thread Part
                          style, mid_outer_diameter, mid_height, 0, 0,                  // Middle Part
                          lower_outer_to_inner_corr, wall_thickness, lower_length       // Lower Part
    );

    rotate([ 0, 180, 0 ]) Adapter_External_Bare(corrector, thread_type, turns, wall_thickness,
                                                entry_chamfer, // Upper External Thread Part
                                                style, mid_outer_diameter, mid_height, 0, 0,            // Middle Part
                                                lower_outer_to_inner_corr, wall_thickness, lower_length // Lower Part
    );
}

// generateNut module to create the nut for the pipe fitting
module generateNut(corrector, thread_type, turns, wall_thickness, entry_chamfer, style, cap_diameter = 0, cap_thickness,
                   z_fite = 0.05, input_dia, tol_pipe, fudge)
{
    {
        difference()
        {

            Adapter_Internal_Cap(corrector, wall_thickness, // corrector, min_wall_size
                                 str(remove_last_chars(thread_type, 4), "-int"), turns, entry_chamfer, style,
                                 cap_diameter, // Upper Internal Thread Part
                                 cap_thickness // Cap Part
            );
            cylinder(h = cap_thickness + z_fite, r = (input_dia / 2 + tol_pipe) * fudge, $fn = 120, center = true);
        }
    }
}

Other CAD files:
adapter_external-bare.scad
Adapters_Mod/AdapterGenerator.scad
Adapters_Mod/Adapter_External-Bare.scad
Adapters_Mod/Adapter_Internal-Cap.scad
adaptersMod-scad/Adapter_External-Bare.scad
adaptersMod-scad/Adapter_Internal-Cap.scad
adaptersMod/AdapterGenerator.scad
adaptersMod/externalToPipe.scad
adaptersMod/internalToPipe.scad
examples/base_example.scad
pipe-joints/Adapter_External-Bare.scad
pipeFittingDesigner.scad

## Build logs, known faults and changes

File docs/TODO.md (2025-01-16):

# TODO

## Enhancements

These are things to improve the existing function of the lib, either performance or usability.

- Clean up API by having defaults for certain function calls

## Features

These are things that are new to extend the function of the lib.

### Multi - intersect joints

- Ability to accept general input requirements to a junction something like:

```json
{
  "connections": [
    {
      "unitvec": [-x,y,z],
      "angle": 0,
      "id": 10,
      "od": 12
    },
    {
      "unitvec": [-x,y,-z],
      "angle": 90,
      "id": 8,
      "od": 10
    }
  ]
}
```

### Common HVAC Connectors and Fittings

- **Press-Fit Fittings:** They compress a gasket between the fitting and pipe. 3D printed versions need to ensure the right balance between tightness and not damaging the gasket.

- **Compression Fittings:** These join two pipes or a pipe to a fixture using a nut and ferrule for a seal. Need to consider material strength for 3D printing to ensure they can handle the pressure without deforming.

- **Flare Fittings:** Designed for high-pressure applications with a flared pipe end sealed by a nut. The 3D printed version must have precise angles and smooth surfaces to ensure a proper seal.

- **Sweat Fittings:** Copper fittings soldered to the pipe. For 3D printing, look into creating a mock-soldered appearance for ease of identification, although actual soldering won't be applicable.

- **Threaded Fittings:** These have male or female threads and require a sealant. Try to design to be sealant-less and consider that threads must be accurately printed to ensure they are leak-proof and compatible with standard pipes.

- **Crimp Fittings:** Used with PEX piping and require a crimp ring. Ensure the 3D printed part can withstand the crimping force without cracking.

- **Push-Fit Fittings:** Allow for easy connection and disconnection without tools. The internal gripping mechanism must be designed to secure the pipe firmly in 3D printed versions.

- **Barbed Fittings:** For use with flexible tubing, secured with a clamp. The barb must be designed to prevent pipe damage in 3D printed versions.

- **Quick Disconnect Fittings:** Designed for easy disconnection and reconnection. The 3D printed design should focus on ease of use while maintaining a secure connection.

- **Ball Valves and Gate Valves:** Used for controlling flow and must match the pipe size and type. The 3D printed design should ensure smooth operation and proper sealing.

- **Rotolock Valves:** Threaded valves for compressor connections. The 3D printed threads need to be precise and may require post-processing for smoothness.

- **Union Fittings:** Designed for easy removal, they must be accurately printed to ensure easy disassembly and a good seal when connected.

- **Capillary Tubes:** Not a fitting but a refrigerant flow control component that connects to fittings. For 3D printing, focus on the internal diameter precision.

- **Schraeder Valves:** Used for refrigerant charging. The 3D printed version must ensure that the valve core fits securely and is leak-proof.

####

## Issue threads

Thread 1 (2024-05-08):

fix floating threads

CameronBrooks11, 2024-05-08:
When certain parameter combinations are use it produces a "pigs tail" structure where the body of the screw is gone and leaves a hanging threads at the end

Closed 2025-01-16.

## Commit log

2024-02-09 fixed rendering error from testing artifact
    [pf_assembly.scad, pf_gasket.scad, pf_main.scad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]
2024-05-29 local push
    [OD10mm_A.scad, OD10mm_A_PC-ABS.3mf, OD10mm_A_PC-ABS1.3mf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]
2024-06-06 added pipe-joints which extends Universal customizable OPENSCAD thread and pipe joint generator...
    [AdapterGenerator.scad, Adapter_External-External.scad, Adapter_Internal-External.scad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]
2024-06-07 finished new attachment head with improved threads and modularity
    [AdapterGenerator.scad, Adapter_External-Bare.scad, OD10mm_A.scad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]
2024-06-07 trimming down of unused assets
    [AdapterGenerator.scad, Adapter_External-External.scad, Adapter_Internal-External.scad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]
2024-06-09 completed all geometry units for new rev, gasket remaining
    [AdapterGenerator.scad, Adapter_External-Bare.scad, Adapter_Internal-Cap.scad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]
2024-07-24 completion of new version
    [AdapterGenerator.scad, Adapter_External-Bare.scad, Adapter_Internal-Cap.scad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]
2024-07-31 Added variable to add length to gasket to improve fit/seal and changed some defautls in designer file
    [pipeFitting.scad, pipeFittingDesigner.scad]
2024-08-28 added flowchart for paper overviewing the scad design
    [AdapterGenerator.scad, externalToPipe.scad, internalToPipe.scad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]
2024-08-29 added variable to access nut wall thickness based on failure mode during testing
    [AdapterGenerator.scad, externalToPipe.scad, internalToPipe.scad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]
2024-09-16 made some minor changes to how the pipe fit length is handled so its more intuitive to users
    [externalToPipe.scad, pfDesigner.scad, pipeFitting.scad]
2024-10-09 cleaned up legacy items and added nice images from publication
    [Gasket01.STEP, Main01.STEP, Nut01.STEP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]
2025-01-16 removed large reference comment block and moved to docs
    [AdapterGenerator.scad, externalToPipe.scad, internalToPipe.scad]
2025-01-16 added JSON file for parameter sets, included default 10mm and 20mm variations
    [pfDesigner.scad, pipeFitting.scad, test1.scad]
2025-02-06 added base example for showing parameterization
    [base_example.scad]
2025-03-09 updated base example
    [base_example.scad]
2026-11-06 fix(presets): match the fittings archived on OSF (#12)
    The `10mm_test` and `20mm_test` presets now reproduce the fittings and
    nuts archived on OSF. Only `middle_length` and `transition_length`
    change.
    Rendered from the presets in this branch and compared with the OSF STLs,
    as (volume cm³, x, y, z mm):
    ```
    10mm_test fitting preset=(7.963, 21.075, 20.225, 64.4) osf=(7.963, 21.075, 20.225, 64.4) MATCH
    20mm_test fitting preset=(20.681, 33.201, 32.455, 86.609) osf=(20.681, 33.201, 32.455, 86.609) MATCH
    10mm_test nut preset=(6.944, 33.161, 28.718, 15.71) osf=(6.944, 33.161, 28.718, 15.71) MATCH
    20mm_test nut preset=(26.56, 52.428, 45.404, 25.01) osf=(26.56, 52.428, 45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
2026-11-06 docs(readme): point Table 3's values to their tag (#13)
    Adds the tag `archive/table-3` at `7a59d5b` to the README's Publication
    Archive section. That is the direct parent of `d9eaef7`, which replaced
    `lower_length` and `mid_height`. The tag is already pushed, so the link
    works.
    A clean `git archive` of `7a59d5b`, rendered with Table 3's values and
    compared with the OSF STLs, as (volume cm³, x, y, z mm):
    10 mm fitting ['12-UN-13/16-ext'] table3=(7.963, 21.075, 20.225, 64.4) osf=(7.963, 21.075, 20.225, 64.4) MATCH
    20 mm fitting ['M33-ext'] table3=(20.681, 33.201, 32.455, 86.609) osf=(20.681, 33.201, 32.455, 86.609) MATCH
    10 mm nut ['12-UN-13/16-ext'] table3=(6.944,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
2026-11-07 docs(readme): complete install steps and publication details (#15)
    Completes the README's install steps and publication details.
    **Install.** The old steps listed only `threadlib`, which also needs
    `scad-utils`, `list-comprehension-demos` and `thread_profile.scad`. I
    followed the new layout in an empty library folder, with threadlib 0.5,
    and rendered with OpenSCAD 2026.10.03 on Linux:
    designer: exit=0 warnings=0 Facets: 27222
    example: exit=0 warnings=0 Facets: 14724
    With `thread_profile.scad` removed, the failure the README now warns
    about appears:
    missing: exit=0 warnings=4 Facets: 6162
    WARNING: Can't open library 'thread_profile.scad'.
    WARNING: Ignoring unknown module '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
2026-11-07 feat(fitting): generate the closed nut and flat gasket (#17)
    The pressure tests closed the far end of each coupling with a capped nut
    and a flat disc gasket. Until now the code could not generate either
    part.
    - `selectedPart = "closed_nut"` is the normal nut with its cap left
    solid. `generateNut` takes a new `closed` argument, false by default.
    - `selectedPart = "flat_gasket"` is a disc as wide as the fitting
    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
2026-11-07 docs(readme): state what the pressure tests do and don't establish (#16)
    Replaces the Performance Testing placeholder with the paper's results,
    the conditions behind them, and what they do not establish.
    **Figures.** Each figure is from the paper's sections 2.3 and 3.2:
    4.551, 2.758, 2.275 and 2.392 MPa, steps of 0.345 MPa held for 180 s,
    ±20 psi, and torques of 12.5, 15, 7.5 and 17.5 Nm. The psi values are
    conversions, for example 4.551 MPa = 660.1 psi. The torque column
    follows the paper's wording: for the 10 mm parts it gives the highest
    torque before cracking, and for 20 mm the torque at which the highest
    pressure was reached.
    **Not in the paper:**
    - The readings were hand-read from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
2026-11-07 feat(fitting): reject inputs that cannot make a working part (#18)
    Inputs that cannot make a working fitting now stop with an error naming
    the input, instead of exporting a part or failing on threadlib's
    `Designator: 'undef' not found`.
    - `pfDesigner.scad` checks that at least one thread matches the
    `gasket_thickness` range, and that `selectedThread` is a whole number in
    range.
    - The new `check_fitting` module in `pipeFitting.scad` checks three
    things: the thread's bore clears the pipe plus `tol_pipe`, `tol_gasket`
    is less than `tol_pipe`, and `gasket_extra_length` is more than the
    thread pitch.
    - The designer and the example both call `check_fitting`, so the checks
    run whichever part is ex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
2026-11-07 fix(fitting): keep the full wall at the tip and clear the Cone seat (#19)
    Two geometry fixes for the fitting.
    **Tip wall.** The entry chamfer's cutter narrowed to `Dsupport / 2 -
    chamfer_size * 2`, inside the thread core, so it cut the fitting wall as
    well as the thread. I added the core cylinder to the cutter's
    subtraction, so only the thread is chamfered. The `else` branch of
    `create_external_threaded_part` has the same shape, but nothing calls it
    with `upper_part = false`, so I left it.
    **Cone collar.** Style `Cone` made its lower tube `mid_height / 2`
    taller than the other styles, so it ran into the gasket seat. It now has
    the same height as the others.
    Assembled as in `examples/base_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
